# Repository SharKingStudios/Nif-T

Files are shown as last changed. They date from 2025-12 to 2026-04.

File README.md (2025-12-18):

<p align="center">
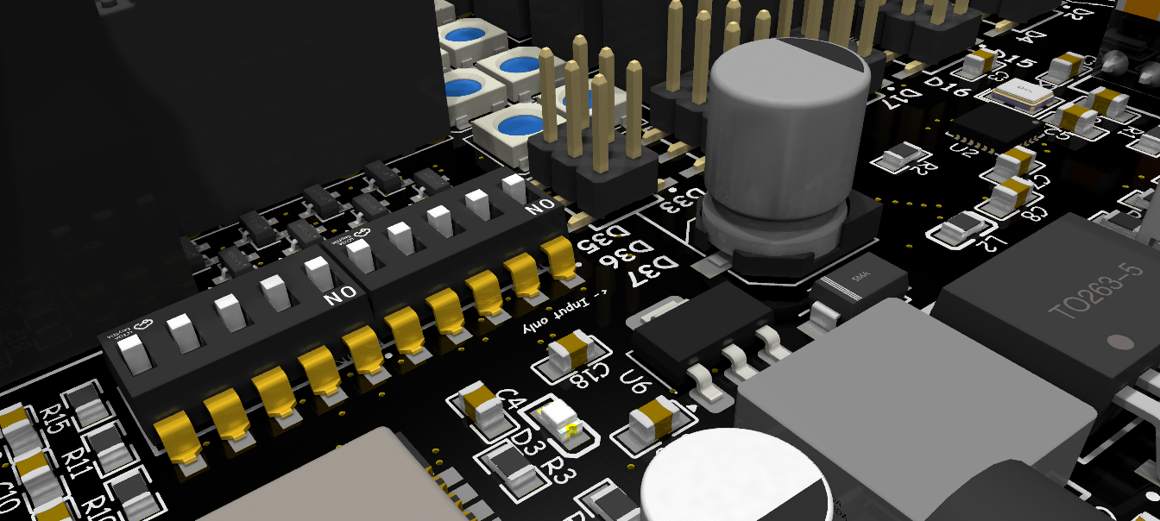
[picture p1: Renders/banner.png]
Banner
  
</p>

# Nif-T - An all in one smart home automation board

### A No-Nonsense Ethernet + PoE Smart-Home Controller

---

## Renders  
*Visuals because everyone loves eye candy.*

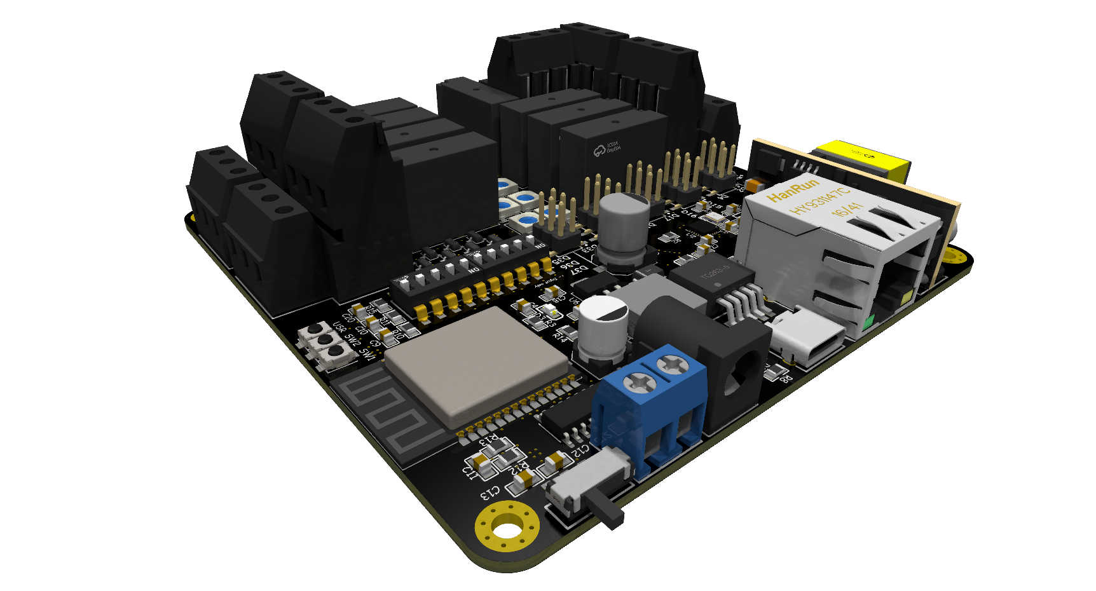
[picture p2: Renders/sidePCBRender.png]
Side PCB Render

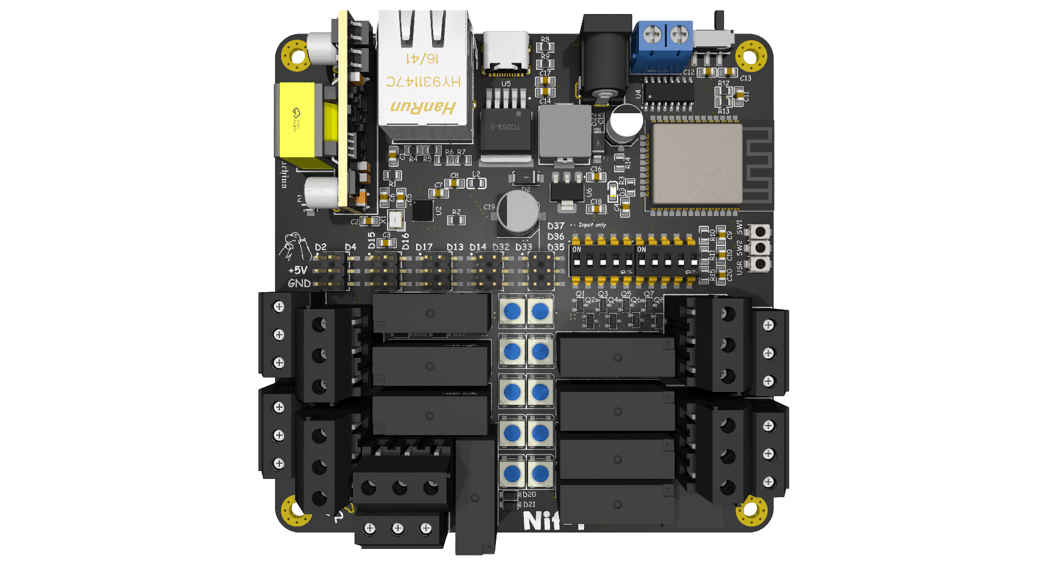
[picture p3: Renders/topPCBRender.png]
Top PCB Render

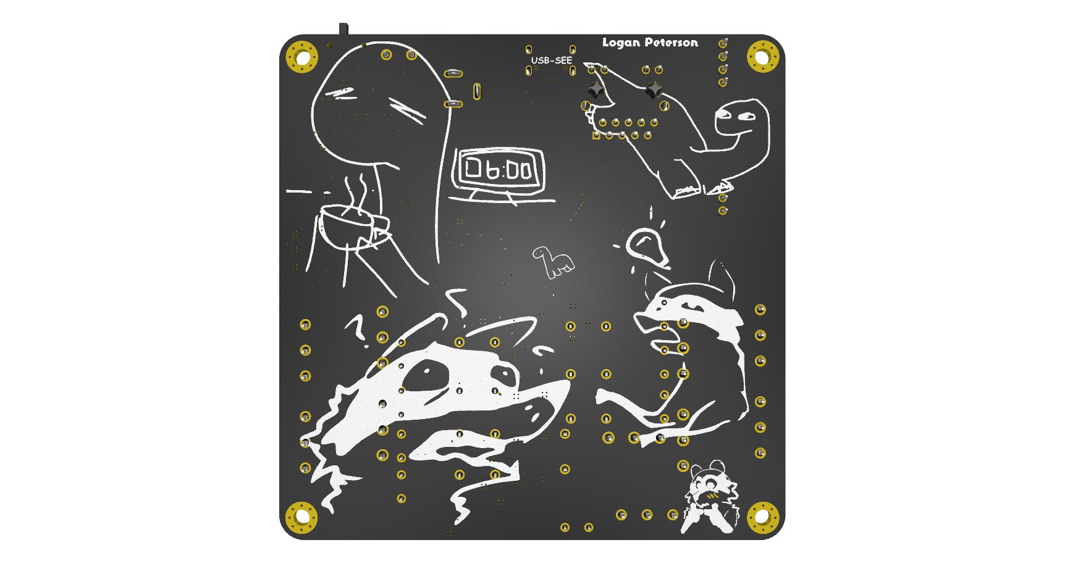
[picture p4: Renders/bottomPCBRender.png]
Bottom PCB Render

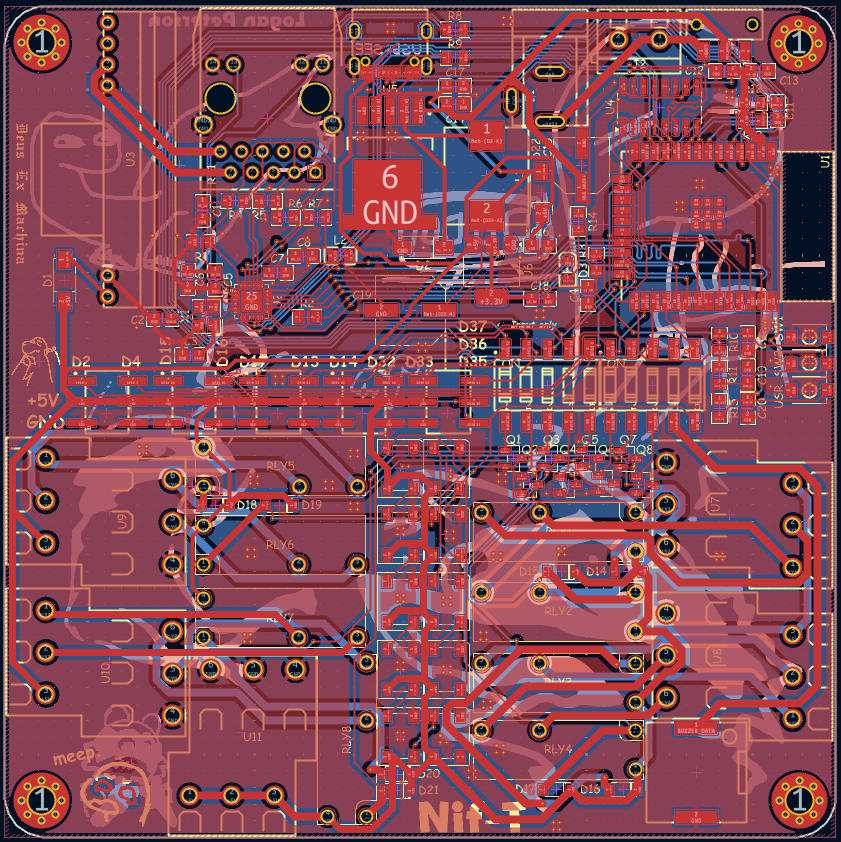
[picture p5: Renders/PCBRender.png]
Routing Glamour Shot

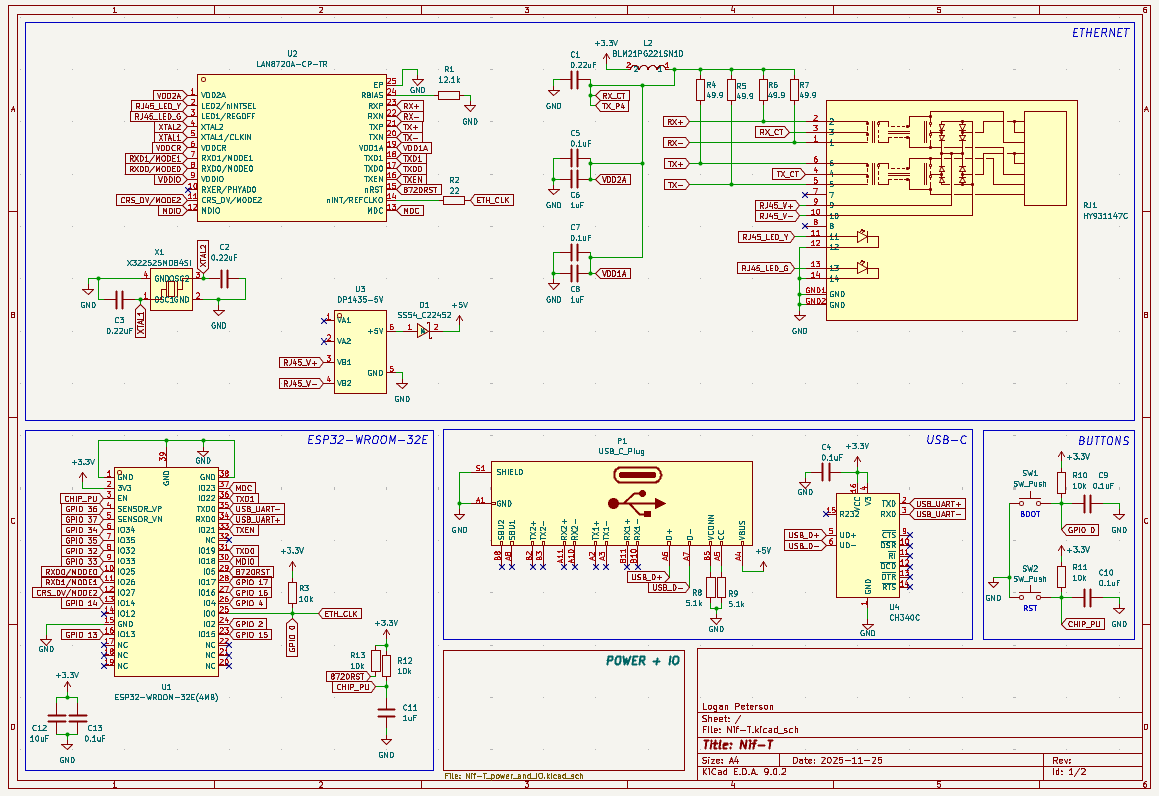
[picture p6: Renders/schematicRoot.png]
Schematic Picture

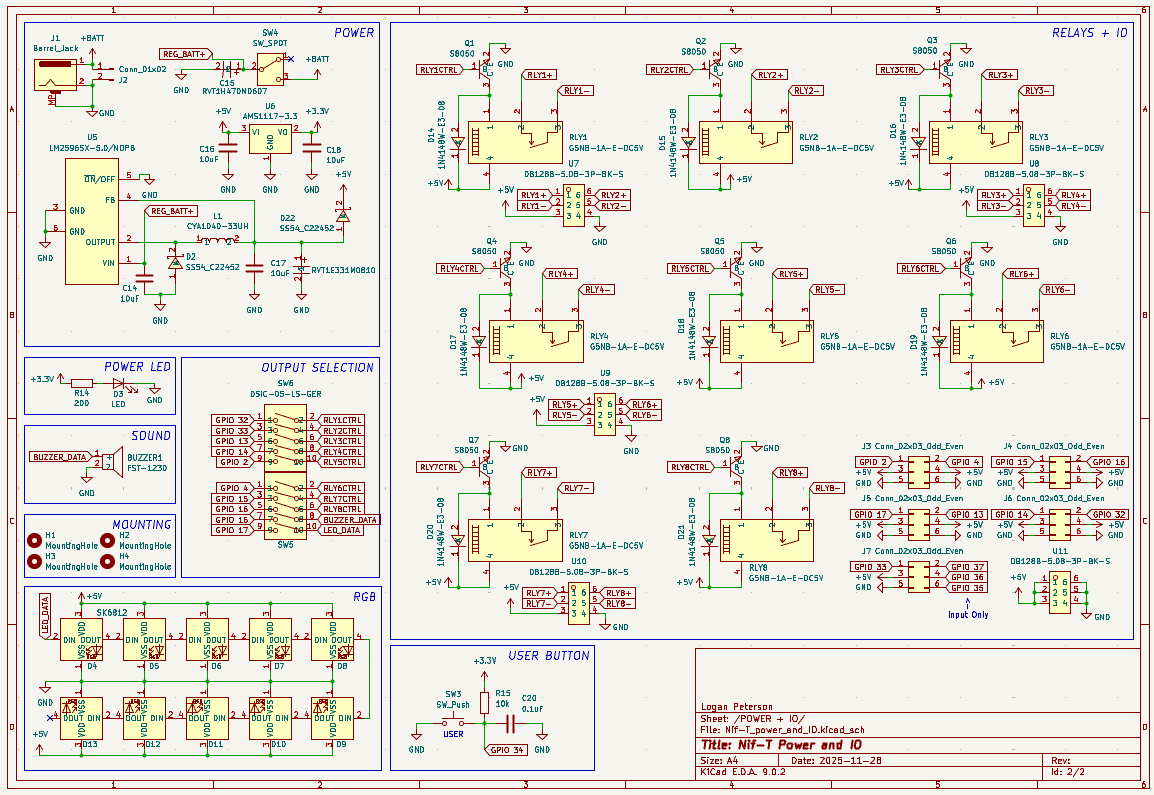
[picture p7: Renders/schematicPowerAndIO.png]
Schematic Picture


> *The middle ground planes are hidden in the PCB Routing render*

---

## BOM  
All the silicon, magnetics, and clicky-relay goodness live **[here](/BOM.csv)**.

**Main characters:**
- **MCU:** ESP32-WROOM-32E
- **Ethernet PHY:** LAN8720A (RMII, external 50 MHz oscillator)
- **Power over Ethernet:** IEEE 802.3af PoE (on-board PD + isolation)
- **Relays:** 8× PCB-mount power relays
- **RGB LEDs:** 10× SK6812 Mini
- **Buzzer:** On-board piezo
- **User Input:** Programmable user button
- **Connectivity:** Ethernet (primary), USB-UART for flashing/debug
- **Power:** PoE-powered with on-board regulation for ESP32 + peripherals
- **Misc:** Boot circuitry, reset logic, pull-ups, decoupling, and other necessary magic

(See `BOM.md` for full part values, footprints, and sourcing.)

---

## What is this?

**Nif-T** is a **wired smart-home automation controller** built around an **ESP32-WROOM-32E**, designed to be the thing that actually flips real switches when you ask your house to do something.

It’s meant for:
- **Lights**
- **Outlets**
- **Relays**
- **Buzzers**
- **Addressable LEDs**
- And other “turn this on when I say so” tasks

Unlike a lot of Wi-Fi-only smart devices, **Nif-T speaks Ethernet** — and it can be powered over the same cable using **PoE**. One cable in, automation out.

At a high level, Nif-T:
- Exposes **physical relays and LEDs**
- Talks to **Home Assistant**
- Which then talks to **Google Home**
- So you can say things like:

> *“Hey Google, turn on the big light.”*

…and something actually happens.

---

## Features

### Relay Control
- **8× independent relay outputs**
- Designed for:
  - Lighting circuits
  - Power control
  - Low-voltage automation tasks
- Each relay is individually addressable via firmware
- Can be controlled via:
  - MQTT
  - Home Assistant
  - Google Home (through HA)

*(Please don’t hot-switch mains unless you know what you’re doing.)*

---

### Ethernet + PoE
Because reliability matters — and wall warts are annoying.

- **LAN8720A Ethernet PHY**
  - RMII interface
  - Dedicated 50 MHz oscillator on the PHY
- **IEEE 802.3af Power over Ethernet**
  - Single-cable power + data
  - On-board PD controller and isolation
  - Clean DC rails generated locally
- No Wi-Fi congestion
- No random disconnects
- No external power brick required

Plug in Ethernet. That’s it.

---

### RGB Status LEDs
Because silent boards are boring.

- **10× SK6812 Mini (GRBW) LEDs**
- Can indicate:
  - Network status
  - MQTT / Home Assistant connection
  - Relay activity
  - Boot / error states
  - Or just run rainbow animations for morale
- Fully firmware-controlled

---

### Buttons & Feedback
- **User button**
  - Can be mapped to:
    - Toggle a relay
    - Enter config mode
    - Trigger a scene
- **On-board buzzer**
  - Boot beeps
  - Error alerts
  - Confirmation chirps
  - Mildly annoying sounds (optional but encouraged)

---

## Connectivity & IO

- **ESP32-WROOM-32E**
  - Dual-core MCU
  - Plenty of GPIO for:
    - Relays
    - LEDs
    - Buttons
    - Buzzers
- **USB-UART**
  - Firmware flashing
  - Serial debugging
- **Screw terminals**
  - For relays and power connections that shouldn’t wiggle loose

---

## Pin Highlights (High-Level)

| Function | Notes |
|---|---|
| Relays | 8× GPIO-controlled outputs |
| LED Data | SK6812 GRBW strip (10 LEDs) |
| Ethernet RMII | LAN8720A w/ external 50 MHz oscillator |
| PoE Input | IEEE 802.3af compliant |
| User Button | Input-only GPIO (external pull-ups) |
| Buzzer | GPIO-driven piezo output |

*(See schematic for full pin mapping and signal names.)*

---

## How It Works

At a high level:

1. **You plug in Ethernet** (which also provides power via PoE)
2. The **PoE PD negotiates power** and generates isolated DC rails
3. The **ESP32 boots** and brings up Ethernet
4. It connects to:
   - An **MQTT broker** (usually Home Assistant)
5. Home Assistant:
   - Discovers Nif-T automatically
   - Exposes relays and LEDs as entities
6. Google Home talks to Home Assistant
7. You talk to Google
8. Nif-T clicks relays and blinks LEDs

---

## Example Use Cases

- “Hey Google, turn on the **workbench lights**”
- “Turn off **everything downstairs**”
- LED status strip that shows:
  - Green = online
  - Red = offline
  - Blue = updating
- Physical button toggles a relay *and* triggers a Home Assistant scene
- Buzzer chirps when automations fire (or silently if you prefer)

---

## Why?

Because:
- Wi-Fi smart plugs are flaky
- Ethernet is king
- PoE makes installs clean
- And sometimes you just want a **solid, hackable, relay board** that plays nicely with modern home automation

Nif-T exists to be:
- Boring in the best way
- Reliable
- Predictable
- And extremely easy to integrate into a real automation stack

---

## Contribute

Ideas, improvements, and constructive roasting welcome.

- Open an **issue**
- Submit a **PR**
- Suggest features
- Argue about relay counts

---

## Disclaimer

This project is open-source, built for fun, and tested only in theory.

If you:
- Wire mains incorrectly
- Ignore clearance rules
- Overload a relay
- Or let the magic smoke out

That’s on you.

Be careful, be smart, and enjoy having a house that actually listens.

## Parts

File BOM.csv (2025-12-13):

Value | Qty | Price Ea. | Price total (MOQ) | LCSC link
RVT1H470M0607 (47uF 50V electrolytic) | 1 | 0.0292 | 0.58 | https://www.lcsc.com/product-detail/C72523.html
RVT1E331M0810 (330uF 25V electrolytic) | 1 | 0.0540 | 0.54 | https://www.lcsc.com/product-detail/C335985.html
1N4148W-E3-08 (SOD-123 fast diode) | 8 | 0.0308 | 0.15 | https://www.lcsc.com/product-detail/C241939.html
CYA1040-33UH (33uH inductor) | 1 | 0.3195 | 1.60 | https://www.lcsc.com/product-detail/C6364680.html
DC-005-A200 (Barrel jack) | 1 | 0.1108 | 0.55 | https://www.lcsc.com/product-detail/C720557.html
0.22uF 0805 | 3 | 0.02 | 0.55 | https://www.lcsc.com/product-detail/C5378.html
Power LED 0805 (D3) | 1 | 0.02 | 0.66 | https://www.lcsc.com/product-detail/C7371915.html
12.1k ohm 0805 (R1) | 1 | 0.03 | 0.73 | https://www.lcsc.com/product-detail/C865169.html
22 ohm 0805 (R2) | 1 | 0.002 | 0.20 | https://www.lcsc.com/product-detail/C17561.html
49.9 ohm 0805 | 4 | 0.002 | 0.18 | https://www.lcsc.com/product-detail/C2933455.html
5.1k ohm 0805 | 2 | 0.002 | 0.19 | https://www.lcsc.com/product-detail/C27834.html
10k ohm 0805 | 6 | 0.002 | 0.19 | https://www.lcsc.com/product-detail/C84376.html
200 ohm 0805 | 1 | 0.002 | 0.14 | https://www.lcsc.com/product-detail/C2933534.html
Crystal Oscillator X322525MOB4SI | 1 | 0.07 | 0.68 | https://www.lcsc.com/product-detail/C9006.html
AMS1117-3.3 | 1 | 0.16 | 0.83 | https://www.lcsc.com/product-detail/C6186.html
TI LM2596SX-5.0/NOPB | 1 | 0.86 | 0.86 | https://www.lcsc.com/product-detail/C10002.html
WCH CH340C | 1 | 0.54 | 0.54 | https://www.lcsc.com/product-detail/C84681.html
MICROCHIP LAN8720A-CP-TR | 1 | 0.73 | 0.73 | https://www.lcsc.com/product-detail/C45223.html
ESPRESSIF ESP32-WROOM-32E-N8 | 1 | 4.11 | 4.11 | https://www.lcsc.com/product-detail/C701342.html
USB-C Port | 1 | 0.05 | 0.49 | https://www.lcsc.com/product-detail/C2927038.html
Ethernet Port (With Magnetics) | 1 | 2.38 | 2.38 | https://www.lcsc.com/product-detail/C91754.html
FST-1230 (Buzzer) | 1 | 0.46 | 0.46 | https://www.lcsc.com/product-detail/C391037.html
SS54 (Schottky diode) | 3 | 0.05 | 0.43 | https://www.lcsc.com/product-detail/C22452.html
SK6812 RGB LED (5050) | 10 | 0.09 | 0.86 | https://www.lcsc.com/product-detail/C5378720.html
CL21B104KBCNNNC (0.1uF 50V X7R 0805) | 7 | 0.006 | 0.30 | https://www.lcsc.com/product-detail/C1711.html
CL21B105KBFNNNE (1uF 50V X7R 0805) | 3 | 0.009 | 0.18 | https://www.lcsc.com/product-detail/C28323.html
CL21A106KAYNNNE (10uF 25V X5R 0805) | 5 | 0.01 | 0.20 | https://www.lcsc.com/product-detail/C15850.html
BLM21PG221SN1D (ferrite bead) | 1 | 0.02 | 0.82 | https://www.lcsc.com/product-detail/C85840.html
S8050 NPN transistor | 8 | 0.0057 | 0.57 | https://www.lcsc.com/product-detail/C916390.html
OMRON G5NB-1A-E-DC5V | 8 | 0.43 | 3.37 | https://www.lcsc.com/product-detail/C48746.html
KF301-5.0-2P (5.00mm 2P terminal block) | 1 | 0.09 | 0.44 | https://www.lcsc.com/product-detail/C474881.html
ZHOURI PZ2.54-2*20-SMT | 2 | 0.24 | 1.2 | https://www.lcsc.com/product-detail/C5378173.html
DORABO DB128B-5.08-2*3P-BK-S | 5 | 0.65 | 3.20 | https://www.lcsc.com/product-detail/C500038.html
SDAPO DP1435-5V | 1 | 4.94 | 4.94 | https://www.lcsc.com/product-detail/C5380097.html
XUNPU DSIC-05-LS-GER | 2 | 0.32 | 0.63 | https://www.lcsc.com/product-detail/C7471367.html
XUNPU TS-1088-AR02016 | 3 | 0.05 | 0.42 | https://www.lcsc.com/product-detail/C720477.html
MST-12D18G4 SPDT Slide Switch | 1 | 0.08 | 0.36 | https://www.lcsc.com/product-detail/C49023767.html
SK6812MINI-HS (extra for dif proj) | 80 | 0.08 | 6.18 | https://www.lcsc.com/product-detail/C2922787.html
LCSC Merchandise Subtotal |  |  |  | 41.96
LCSC Shipping Estimate |  |  |  | 15.12
LCSC Taxes Buffer |  |  |  | 5.00
LCSC Total |  |  |  | 62.08
JLCPCB Fabrication | 5 |  |  | 2.00
JLCPCB Stencil | 1 |  |  | 7.00
JLCPCB Shipping Estimate |  |  |  | 16.50
JLCPCB Taxes Buffer |  |  |  | 3.00
JLCPCB Total |  |  |  | 28.50
Grand Total |  |  |  | 90.58
Reimbursement amount |  |  |  | 6.18

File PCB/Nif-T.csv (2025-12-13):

Reference | Qty | Value | DNP | Exclude from BOM | Exclude from Board | Footprint | Datasheet
BUZZER1 | 1 | FST-1230 |  |  |  | imported_components:BUZ-SMD_L12.0-W12.0_FUET-1230 | https://lcsc.com/product-detail/Buzzers_FST-FST-1230_C391037.html
C1,C2,C3 | 3 | 0.22uF |  |  |  | imported_components:C0805 | ~
C4,C5,C7,C9,C10,C13,C20 | 7 | 0.1uF |  |  |  | imported_components:C0805 | ~
C6,C8,C11 | 3 | 1uF |  |  |  | imported_components:C0805 | ~
C12,C14,C16,C17,C18 | 5 | 10uF |  |  |  | imported_components:C0805 | ~
C15 | 1 | RVT1H470M0607 |  |  |  | imported_components:CAP-SMD_BD6.3-L6.6-W6.6-LS7.6-FD | https://lcsc.com/product-detail/Aluminum-Electrolytic-Capacitors-SMD_47uF-50V-20_C72523.html
C19 | 1 | RVT1E331M0810 |  |  |  | imported_components:CAP-SMD_BD8.0-L8.3-W8.3-LS9.3-FD-1 | https://lcsc.com/product-detail/Others_ROQANG-RVT1E331M0810_C335985.html
D1,D2,D22 | 3 | SS54_C22452 |  |  |  | imported_components:SMA_L4.4-W2.8-LS5.4-R-RD | https://lcsc.com/product-detail/Schottky-Barrier-Diodes-SBD_SS54_C22452.html
D3 | 1 | LED |  |  |  | imported_components:LED0805-RD | ~
D4,D5,D6,D7,D8,D9,D10,D11,D12,D13 | 10 | SK6812 |  |  |  | LED_SMD:LED_SK6812_PLCC4_5.0x5.0mm_P3.2mm | https://cdn-shop.adafruit.com/product-files/1138/SK6812+LED+datasheet+.pdf
D14,D15,D16,D17,D18,D19,D20,D21 | 8 | 1N4148W-E3-08 |  |  |  | new_imported_components:SOD-123_L2.8-W1.8-LS3.7-RD | https://lcsc.com/product-detail/Others_Vishay-Intertech_1N4148W-E3-08_Vishay-Intertech-1N4148W-E3-08_C241939.html
H1,H2,H3,H4 | 4 | MountingHole |  | Excluded from BOM |  | MountingHole:MountingHole_3.2mm_M3_Pad_Via | ~
J1 | 1 | Barrel_Jack |  |  |  | imported_components:DC-IN-TH_DC-005-A200 | ~
J2 | 1 | Conn_01x02 |  |  |  | imported_components:CONN-TH_P5.00_KF301-5.0-2P | ~
J3,J4,J5,J6,J7 | 5 | Conn_02x03_Odd_Even |  |  |  | imported_components:HDR-SMD_6P-P2.54-V | ~
L1 | 1 | CYA1040-33UH |  |  |  | imported_components:IND-SMD_L11.6-W10.1
L2 | 1 | BLM21PG221SN1D |  |  |  | new_imported_components:L0805 | https://lcsc.com/product-detail/Ferrite-Beads-And-Chips_muRata_BLM21PG221SN1D_220R-25-at100MHz-2A_C85840.html
P1 | 1 | USB_C_Plug |  |  |  | imported_components:USB-C_SMD-TYPE-C-31-M-12 | https://www.usb.org/sites/default/files/documents/usb_type-c.zip
Q1,Q2,Q3,Q4,Q5,Q6,Q7,Q8 | 8 | S8050 |  |  |  | new_imported_components:SOT-23-3_L2.9-W1.3-P1.90-LS2.4-BR | https://lcsc.com/product-detail/Transistors-NPN-PNP_JSMSEMI-S8050_C916390.html
R1 | 1 | 12.1k |  |  |  | imported_components:R0805 | ~
R2 | 1 | 22 |  |  |  | imported_components:R0805 | ~
R3,R10,R11,R12,R13,R15 | 6 | 10k |  |  |  | imported_components:R0805 | ~
R4,R5,R6,R7 | 4 | 49.9 |  |  |  | imported_components:R0805 | ~
R8,R9 | 2 | 5.1k |  |  |  | imported_components:R0805 | ~
R14 | 1 | 200 |  |  |  | imported_components:R0805 | ~
RJ1 | 1 | HY931147C |  |  |  | new_imported_components:RJ45-TH_HY931147C | https://lcsc.com/product-detail/RJ45_HY931147C_C91754.html
RLY1,RLY2,RLY3,RLY4,RLY5,RLY6,RLY7,RLY8 | 8 | G5NB-1A-E-DC5V |  |  |  | new_imported_components:RELAY-TH_G5NB-1A-E-DCXX | https://lcsc.com/product-detail/Relays_OMRON_G5NB-1A-E-DC5V_G5NB-1A-E-DC5V_C48746.html
SW1,SW2,SW3 | 3 | SW_Push |  |  |  | imported_components:SW-SMD_L3.9-W3.0-P4.45 | ~
SW4 | 1 | SW_SPDT |  |  |  | imported_components:SW-SMD_MST-12D18G4-SPDT-SLIDE-SWITCH | ~
SW5,SW6 | 2 | DSIC-05-LS-GER |  |  |  | new_imported_components:SW-SMD_DSIC-05-LS-GER
U1 | 1 | ESP32-WROOM-32E(4MB) |  |  |  | new_imported_components:WIFI-SMD_ESP32-WROOM-32E | https://lcsc.com/product-detail/WIFI-Modules_Espressif-Systems-ESP32-WROOM-32E-4MB_C701341.html
U2 | 1 | LAN8720A-CP-TR |  |  |  | new_imported_components:QFN-24_L4.0-W4.0-P0.50-BL-EP2.6 | https://lcsc.com/product-detail/Ethernet-ICs_LAN8720A-CP-TR_C45223.html
U3 | 1 | DP1435-5V |  |  |  | new_imported_components:PWRM-TH_DP1435-XX
U4 | 1 | CH340C |  |  |  | Package_SO:SOIC-16_3.9x9.9mm_P1.27mm | https://datasheet.lcsc.com/szlcsc/Jiangsu-Qin-Heng-CH340C_C84681.pdf
U5 | 1 | LM2596SX-5.0/NOPB |  |  |  | imported_components:TO-263-5_L10.2-W8.9-P1.70-TL | https://lcsc.com/product-detail/DC-DC-Converters_TI_LM2596SX-5-0-NOPB_LM2596SX-5-0-NOPB_C10002.html
U6 | 1 | AMS1117-3.3 |  |  |  | Package_TO_SOT_SMD:SOT-223-3_TabPin2 | http://www.advanced-monolithic.com/pdf/ds1117.pdf
U7,U8,U9,U10,U11 | 5 | DB128B-5.08-3P-BK-S |  |  |  | new_imported_components:CONN-TH_DB128B-5.08-3P-XX-S | https://lcsc.com/product-detail/New-Arrivals_DIBO-DB128B-5-08-3P-BK-S_C500038.html
X1 | 1 | X322525MOB4SI |  |  |  | new_imported_components:CRYSTAL-SMD_4P-L3.2-W2.5-BL | https://lcsc.com/product-detail/SMD-Crystals_YSX321SL-25MHZ-12PF-10PPM-40-85_C9006.html

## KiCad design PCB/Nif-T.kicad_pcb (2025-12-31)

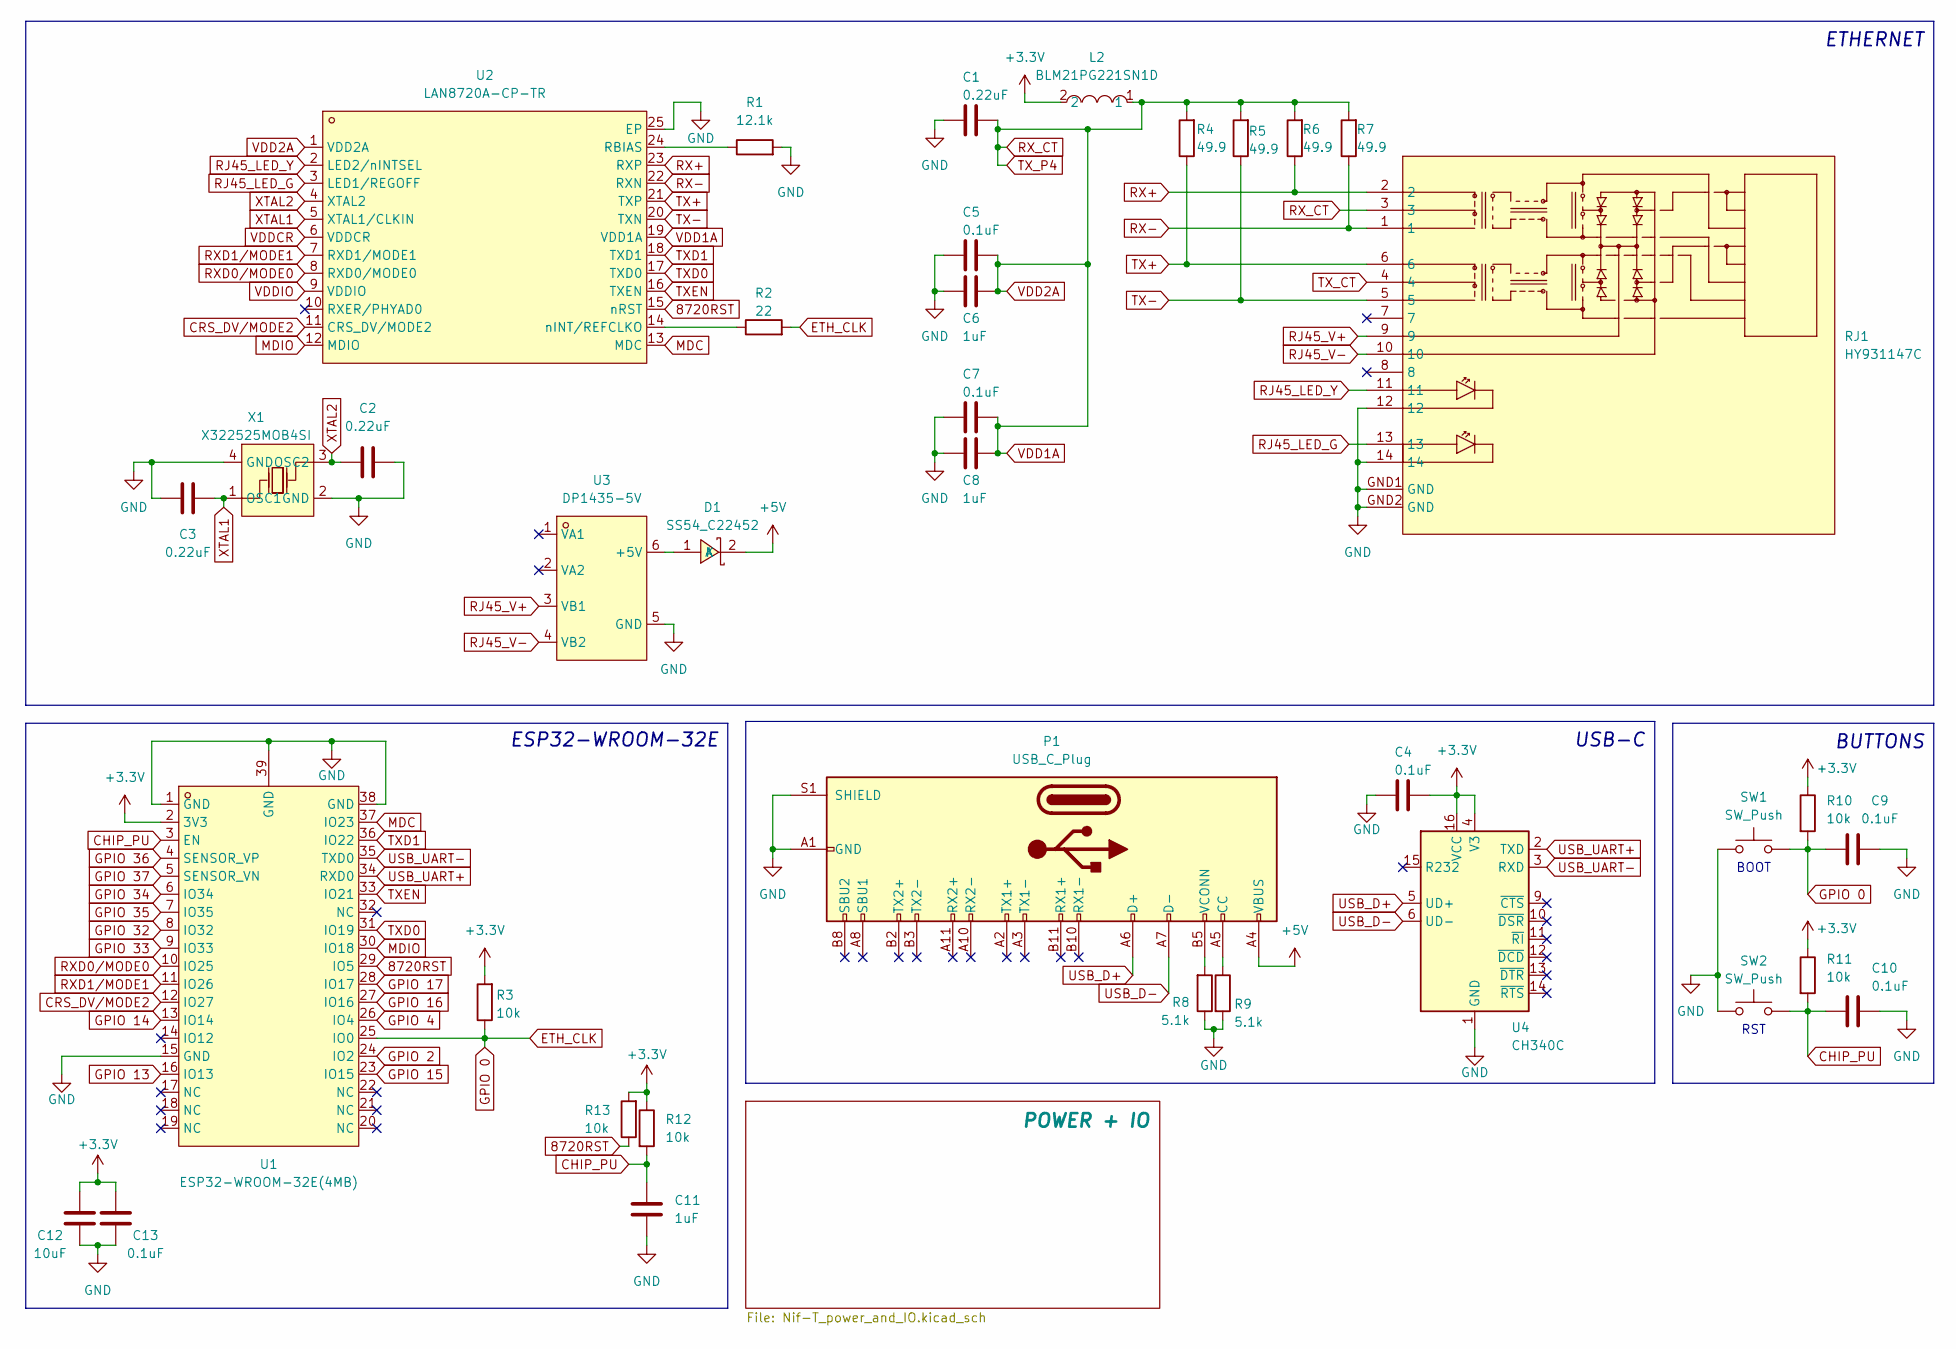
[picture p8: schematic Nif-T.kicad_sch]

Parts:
C1, C2, C3: 0.22uF; C0805
C4, C5, C7, C9, C10, C13: 0.1uF; C0805
C6, C8, C11: 1uF; C0805
C12: 10uF; C0805
D1: SS54_C22452; SMA_L4.4-W2.8-LS5.4-R-RD; LCSC Part C22452
L2: BLM21PG221SN1D; L0805; LCSC Part C85840
P1: USB_C_Plug; USB-C_SMD-TYPE-C-31-M-12
R1: 12.1k; R0805
R2: 22; R0805
R3, R10, R11, R12, R13: 10k; R0805
R4, R5, R6, R7: 49.9; R0805
R8, R9: 5.1k; R0805
RJ1: HY931147C; RJ45-TH_HY931147C; LCSC Part C91754
SW1, SW2: SW_Push; SW-SMD_L3.9-W3.0-P4.45
U1: ESP32-WROOM-32E(4MB); WIFI-SMD_ESP32-WROOM-32E; LCSC Part C701341
U2: LAN8720A-CP-TR; QFN-24_L4.0-W4.0-P0.50-BL-EP2.6; LCSC Part C45223
U3: DP1435-5V; PWRM-TH_DP1435-XX; LCSC Part C5380097
U4: CH340C; SOIC-16_3.9x9.9mm_P1.27mm
X1: X322525MOB4SI; CRYSTAL-SMD_4P-L3.2-W2.5-BL; LCSC Part C9006

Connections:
8720RST: R13.1, U1.29 (IO5), U2.15 (nRST)
+3.3V: C4.1, C12.2, C13.2, L2.2, R3.2, R10.1, R11.1, R12.1, R13.2, U1.2 (3V3), U4.4 (V3), U4.16 (VCC); also elsewhere on the board
+5V: D1.2 (K), P1.A4 (VBUS), P1.A9 (VBUS), P1.B4 (VBUS), P1.B9 (VBUS); also elsewhere on the board
CHIP_PU: C10.1, C11.1, R11.2, R12.2, SW2.1, U1.3 (EN)
CRS_DV/MODE2: U1.12 (IO27), U2.11 (CRS_DV/MODE2)
ETH_CLK: C9.1, R2.2, R3.1, R10.2, SW1.1, U1.25 (IO0)
GND: C1.2, C2.2, C3.1, C4.2, C5.2, C6.2, C7.2, C8.2, C9.2, C10.2, C11.2, C12.1, C13.1, P1.A1 (GND), P1.A12 (GND), P1.B1 (GND), P1.B12 (GND), P1.S1 (SHIELD), R1.2, R8.1, R9.2, RJ1.12, RJ1.14, RJ1.GND1 (GND), RJ1.GND2 (GND), SW1.2, SW2.2, U1.1 (GND), U1.15 (GND), U1.38 (GND), U1.39 (GND), U2.25 (EP), U3.5 (GND), U4.1 (GND), X1.2 (GND), X1.4 (GND); also elsewhere on the board
GPIO 2: U1.24 (IO2); also elsewhere on the board
GPIO 4: U1.26 (IO4); also elsewhere on the board
GPIO 13: U1.16 (IO13); also elsewhere on the board
GPIO 14: U1.13 (IO14); also elsewhere on the board
GPIO 15: U1.23 (IO15); also elsewhere on the board
GPIO 16: U1.27 (IO16); also elsewhere on the board
GPIO 17: U1.28 (IO17); also elsewhere on the board
GPIO 32: U1.8 (IO32); also elsewhere on the board
GPIO 33: U1.9 (IO33); also elsewhere on the board
GPIO 34: U1.6 (IO34); also elsewhere on the board
GPIO 35: U1.7 (IO35); also elsewhere on the board
GPIO 36: U1.4 (SENSOR_VP); also elsewhere on the board
GPIO 37: U1.5 (SENSOR_VN); also elsewhere on the board
MDC: U1.37 (IO23), U2.13 (MDC)
MDIO: U1.30 (IO18), U2.12 (MDIO)
unnamed: D1.1 (A), U3.6 (+5V)
unnamed: P1.A5 (CC), R9.1
unnamed: P1.B5 (VCONN), R8.2
unnamed: R1.1, U2.24 (RBIAS)
unnamed: R2.1, U2.14 (nINT/REFCLKO)
RJ45_LED_G: RJ1.13, U2.3 (LED1/REGOFF)
RJ45_LED_Y: RJ1.11, U2.2 (LED2/nINTSEL)
RJ45_V+: RJ1.9, U3.3 (VB1)
RJ45_V-: RJ1.10, U3.4 (VB2)
RX+: R6.1, RJ1.2, U2.23 (RXP)
RX-: R7.1, RJ1.1, U2.22 (RXN)
RXD0/MODE0: U1.10 (IO25), U2.8 (RXD0/MODE0)
RXD1/MODE1: U1.11 (IO26), U2.7 (RXD1/MODE1)
RX_CT: C1.1, C5.1, C6.1, C7.1, C8.1, L2.1, R4.2, R5.2, R6.2, R7.2, RJ1.3, U2.1 (VDD2A), U2.19 (VDD1A)
TX+: R4.1, RJ1.6, U2.21 (TXP)
TX-: R5.1, RJ1.5, U2.20 (TXN)
TXD0: U1.31 (IO19), U2.17 (TXD0)
TXD1: U1.36 (IO22), U2.18 (TXD1)
TXEN: U1.33 (IO21), U2.16 (TXEN)
TX_CT: RJ1.4
USB_D+: P1.A6 (D+), U4.5 (UD+)
USB_D-: P1.A7 (D-), U4.6 (UD-)
USB_UART+: U1.34 (RXD0), U4.2 (TXD)
USB_UART-: U1.35 (TXD0), U4.3 (RXD)
VDDCR: U2.6 (VDDCR)
VDDIO: U2.9 (VDDIO)
XTAL1: C3.2, U2.5 (XTAL1/CLKIN), X1.1 (OSC1)
XTAL2: C2.1, U2.4 (XTAL2), X1.3 (OSC2)

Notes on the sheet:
BOOT
ESP32-WROOM-32E
ETHERNET
RST
USB-C
BUTTONS

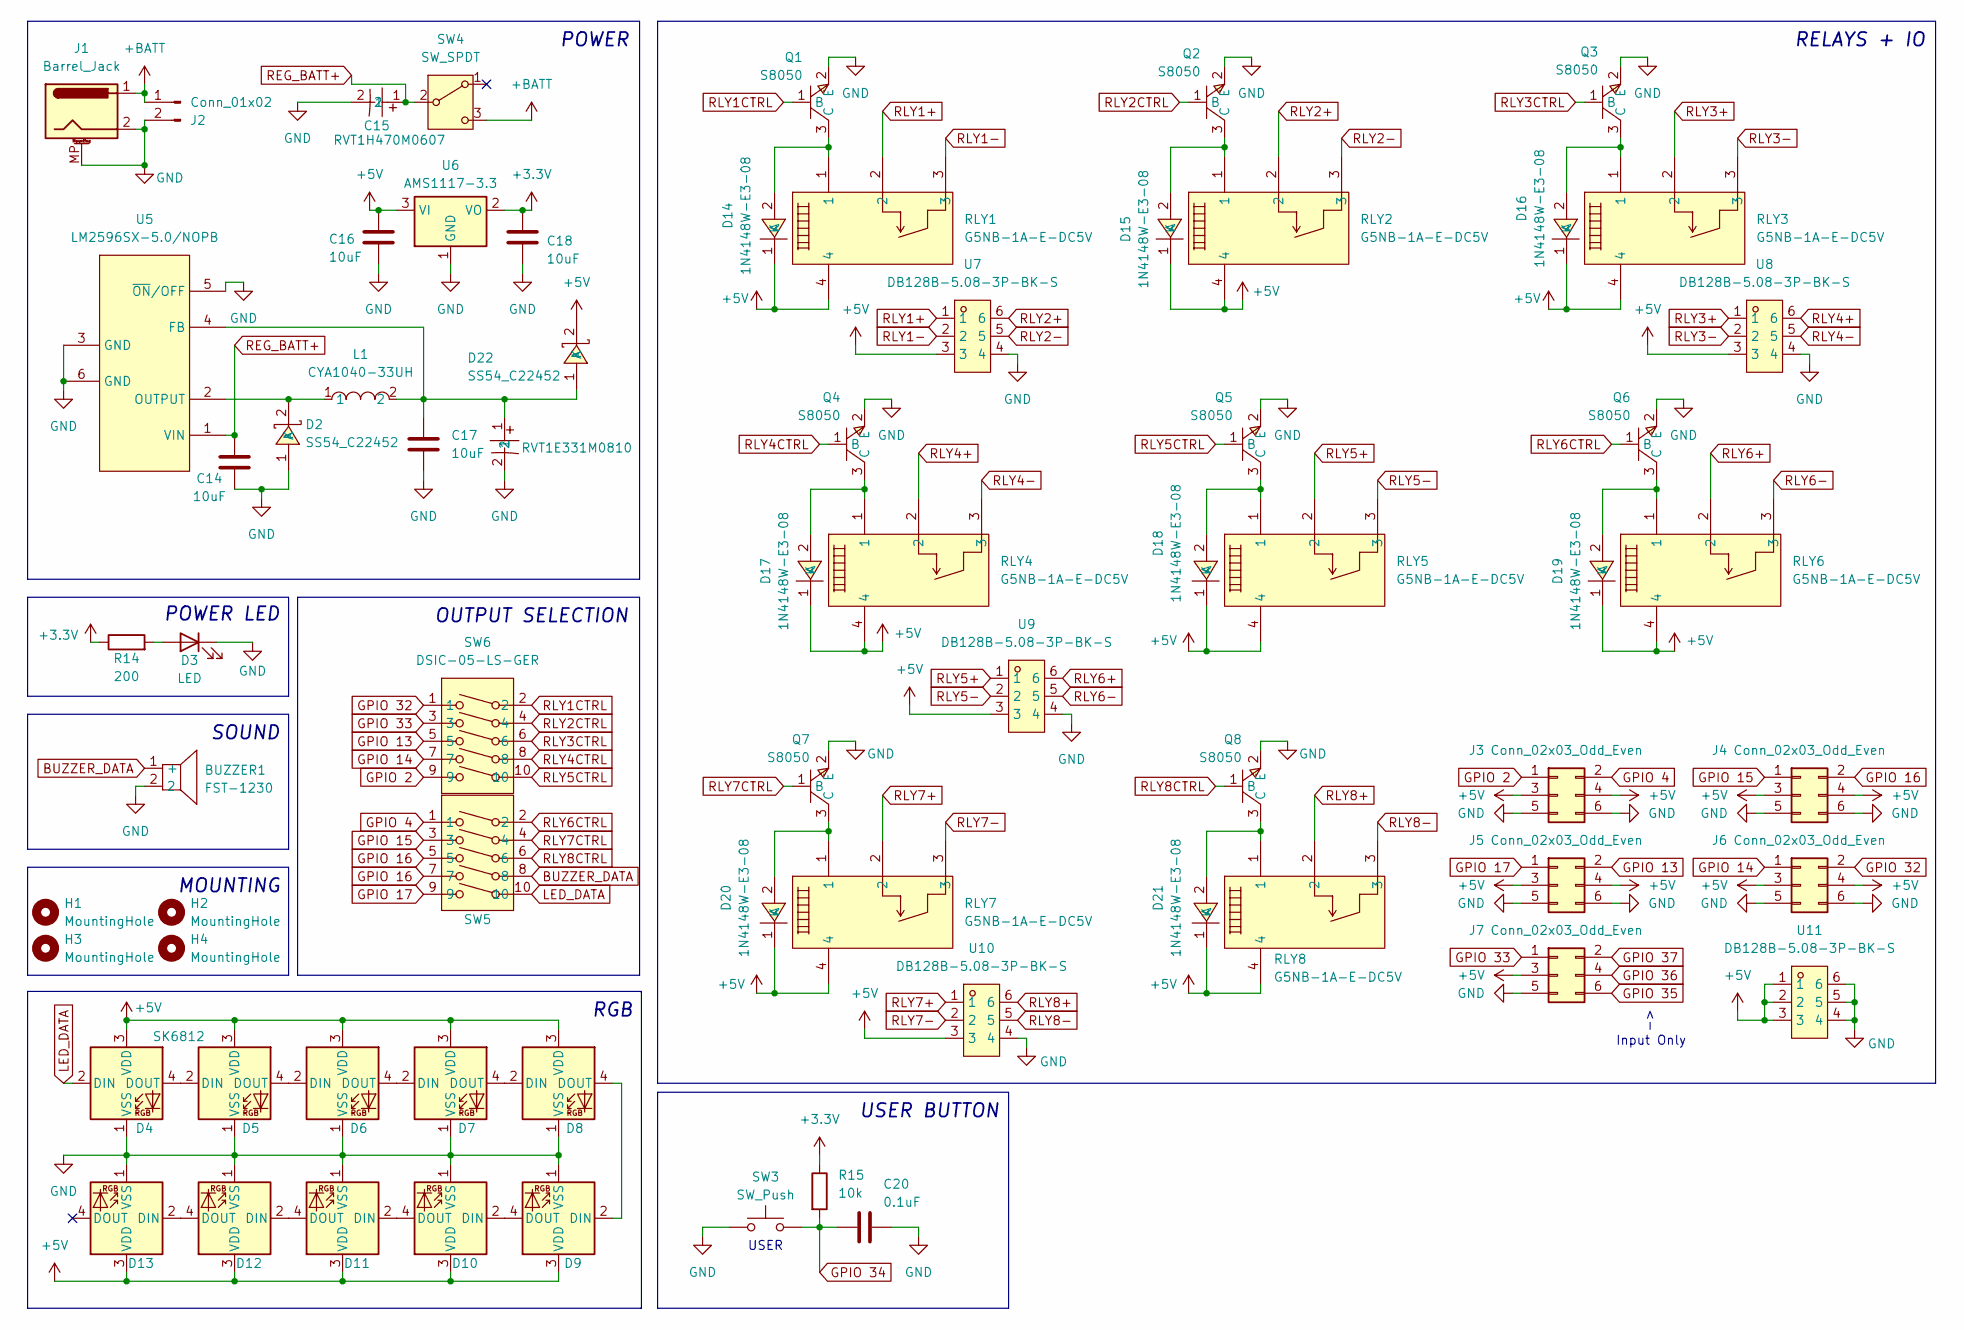
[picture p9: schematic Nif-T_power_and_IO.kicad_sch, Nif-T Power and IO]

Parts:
BUZZER1: FST-1230; BUZ-SMD_L12.0-W12.0_FUET-1230; LCSC Part C391037
C14, C16, C17, C18: 10uF; C0805
C15: RVT1H470M0607; CAP-SMD_BD6.3-L6.6-W6.6-LS7.6-FD; LCSC Part C72523
C19: RVT1E331M0810; CAP-SMD_BD8.0-L8.3-W8.3-LS9.3-FD-1; LCSC Part C335985
C20: 0.1uF; C0805
D2, D22: SS54_C22452; SMA_L4.4-W2.8-LS5.4-R-RD; LCSC Part C22452
D3: LED; LED0805-RD
D4, D5, D6, D7, D8, D9, D10, D11, D12, D13: SK6812; LED_SK6812_PLCC4_5.0x5.0mm_P3.2mm
D14, D15, D16, D17, D18, D19, D20, D21: 1N4148W-E3-08; SOD-123_L2.8-W1.8-LS3.7-RD; LCSC Part C241939
H1, H2, H3, H4: MountingHole; MountingHole_3.2mm_M3_Pad_Via
J1: Barrel_Jack; DC-IN-TH_DC-005-A200
J2: Conn_01x02; CONN-TH_P5.00_KF301-5.0-2P
J3, J4, J5, J6, J7: Conn_02x03_Odd_Even; HDR-SMD_6P-P2.54-V
L1: CYA1040-33UH; IND-SMD_L11.6-W10.1; LCSC Part C6364680
Q1, Q2, Q3, Q4, Q5, Q6, Q7, Q8: S8050; SOT-23-3_L2.9-W1.3-P1.90-LS2.4-BR; LCSC Part C916390
R14: 200; R0805
R15: 10k; R0805
RLY1, RLY2, RLY3, RLY4, RLY5, RLY6, RLY7, RLY8: G5NB-1A-E-DC5V; RELAY-TH_G5NB-1A-E-DCXX; LCSC Part C48746
SW3: SW_Push; SW-SMD_L3.9-W3.0-P4.45
SW4: SW_SPDT; SW-SMD_MST-12D18G4-SPDT-SLIDE-SWITCH
SW5, SW6: DSIC-05-LS-GER; SW-SMD_DSIC-05-LS-GER; LCSC Part C7471367
U5: LM2596SX-5.0/NOPB; TO-263-5_L10.2-W8.9-P1.70-TL; LCSC Part C10002
U6: AMS1117-3.3; SOT-223-3_TabPin2
U7, U8, U9, U10, U11: DB128B-5.08-3P-BK-S; CONN-TH_DB128B-5.08-3P-XX-S; LCSC Part C500038

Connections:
+3.3V: C18.1, R14.1, R15.1, U6.2 (VO); also elsewhere on the board
+5V: C16.1, D4.3 (VDD), D5.3 (VDD), D6.3 (VDD), D7.3 (VDD), D8.3 (VDD), D9.3 (VDD), D10.3 (VDD), D11.3 (VDD), D12.3 (VDD), D13.3 (VDD), D14.1 (K), D15.1 (K), D16.1 (K), D17.1 (K), D18.1 (K), D19.1 (K), D20.1 (K), D21.1 (K), D22.2 (K), J3.3, J3.4, J4.3, J4.4, J5.3, J5.4, J6.3, J6.4, J7.3, RLY1.4, RLY2.4, RLY3.4, RLY4.4, RLY5.4, RLY6.4, RLY7.4, RLY8.4, U6.3 (VI), U7.3, U8.3, U9.3, U10.3, U11.1, U11.2, U11.3; also elsewhere on the board
+BATT: J1.1, J2.1, SW4.3 (C)
BUZZER_DATA: BUZZER1.1 (+), SW5.8
GND: BUZZER1.2, C14.1, C15.2, C16.2, C17.2, C18.2, C19.2, C20.2, D2.1 (A), D3.1 (K), D4.1 (VSS), D5.1 (VSS), D6.1 (VSS), D7.1 (VSS), D8.1 (VSS), D9.1 (VSS), D10.1 (VSS), D11.1 (VSS), D12.1 (VSS), D13.1 (VSS), J1.2, J1.MP (MountPin), J2.2, J3.5, J3.6, J4.5, J4.6, J5.5, J5.6, J6.5, J6.6, J7.5, Q1.2 (E), Q2.2 (E), Q3.2 (E), Q4.2 (E), Q5.2 (E), Q6.2 (E), Q7.2 (E), Q8.2 (E), SW3.2, U5.3 (GND), U5.5 (~ON/OFF), U5.6 (GND), U6.1 (GND), U7.4, U8.4, U9.4, U10.4, U11.4, U11.5, U11.6; also elsewhere on the board
GPIO 2: J3.1, SW6.9; also elsewhere on the board
GPIO 4: J3.2, SW5.1; also elsewhere on the board
GPIO 13: J5.2, SW6.5; also elsewhere on the board
GPIO 14: J6.1, SW6.7; also elsewhere on the board
GPIO 15: J4.1, SW5.3; also elsewhere on the board
GPIO 16: J4.2, SW5.5, SW5.7; also elsewhere on the board
GPIO 17: J5.1, SW5.9; also elsewhere on the board
GPIO 32: J6.2, SW6.1; also elsewhere on the board
GPIO 33: J7.1, SW6.3; also elsewhere on the board
GPIO 34: C20.1, R15.2, SW3.1; also elsewhere on the board
GPIO 35: J7.6; also elsewhere on the board
GPIO 36: J7.4; also elsewhere on the board
GPIO 37: J7.2; also elsewhere on the board
LED_DATA: D4.2 (DIN), SW5.10
unnamed: D2.2 (K), L1.1, U5.2 (OUTPUT)
unnamed: D3.2 (A), R14.2
unnamed: D4.4 (DOUT), D5.2 (DIN)
unnamed: D5.4 (DOUT), D6.2 (DIN)
unnamed: D6.4 (DOUT), D7.2 (DIN)
unnamed: D7.4 (DOUT), D8.2 (DIN)
unnamed: D8.4 (DOUT), D9.2 (DIN)
unnamed: D9.4 (DOUT), D10.2 (DIN)
unnamed: D10.4 (DOUT), D11.2 (DIN)
unnamed: D11.4 (DOUT), D12.2 (DIN)
unnamed: D12.4 (DOUT), D13.2 (DIN)
unnamed: D14.2 (A), Q1.3 (C), RLY1.1
unnamed: D15.2 (A), Q2.3 (C), RLY2.1
unnamed: D16.2 (A), Q3.3 (C), RLY3.1
unnamed: D17.2 (A), Q4.3 (C), RLY4.1
unnamed: D18.2 (A), Q5.3 (C), RLY5.1
unnamed: D19.2 (A), Q6.3 (C), RLY6.1
unnamed: D20.2 (A), Q7.3 (C), RLY7.1
unnamed: D21.2 (A), Q8.3 (C), RLY8.1
unnamed: C17.1, C19.1, D22.1 (A), L1.2, U5.4 (FB)
REG_BATT+: C14.2, C15.1, SW4.2 (B), U5.1 (VIN)
RLY1+: RLY1.2, U7.1
RLY1-: RLY1.3, U7.2
RLY1CTRL: Q1.1 (B), SW6.2
RLY2+: RLY2.2, U7.6
RLY2-: RLY2.3, U7.5
RLY2CTRL: Q2.1 (B), SW6.4
RLY3+: RLY3.2, U8.1
RLY3-: RLY3.3, U8.2
RLY3CTRL: Q3.1 (B), SW6.6
RLY4+: RLY4.2, U8.6
RLY4-: RLY4.3, U8.5
RLY4CTRL: Q4.1 (B), SW6.8
RLY5+: RLY5.2, U9.1
RLY5-: RLY5.3, U9.2
RLY5CTRL: Q5.1 (B), SW6.10
RLY6+: RLY6.2, U9.6
RLY6-: RLY6.3, U9.5
RLY6CTRL: Q6.1 (B), SW5.2
RLY7+: RLY7.2, U10.1
RLY7-: RLY7.3, U10.2
RLY7CTRL: Q7.1 (B), SW5.4
RLY8+: RLY8.2, U10.6
RLY8-: RLY8.3, U10.5
RLY8CTRL: Q8.1 (B), SW5.6

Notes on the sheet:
POWER LED
OUTPUT SELECTION
SOUND
RELAYS + IO
USER
RGB
USER BUTTON
MOUNTING
POWER
Input Only

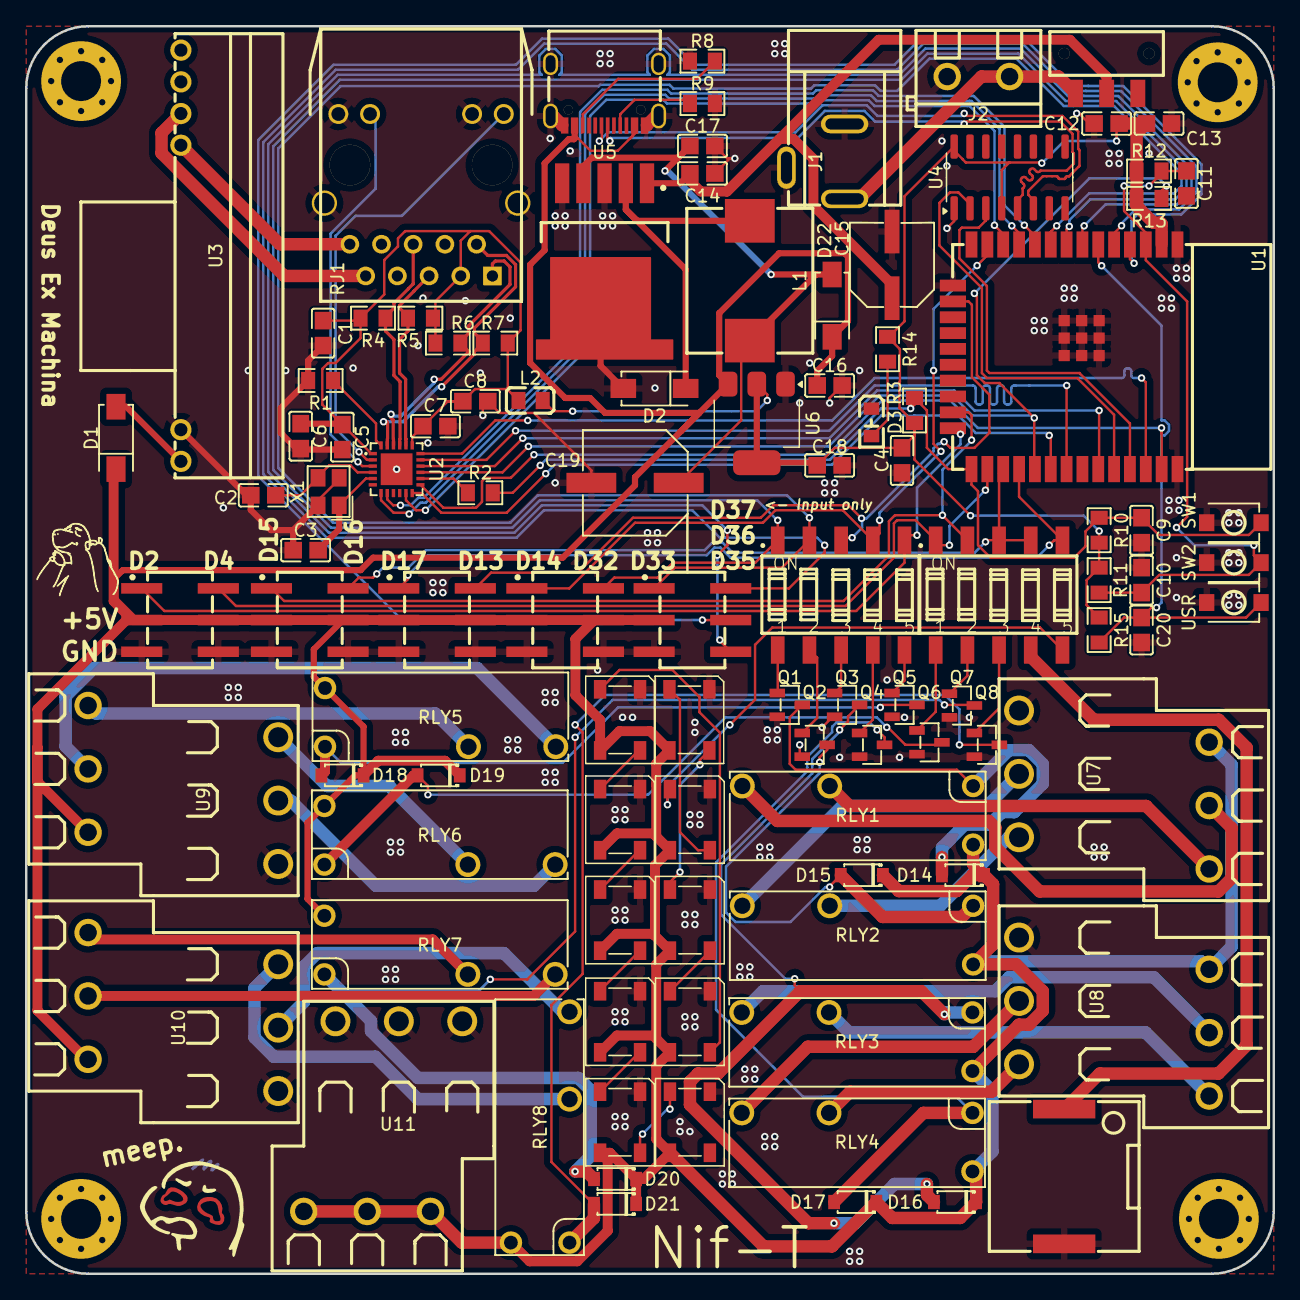
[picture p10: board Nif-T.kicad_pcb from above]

Board: 4 copper layers, 100.0 x 100.0 mm, 107 parts (0 on the bottom side), 95 nets.

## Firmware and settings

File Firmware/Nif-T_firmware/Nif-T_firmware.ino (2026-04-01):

/*
  Nif-T Firmware (ESP32-WROOM-32E + LAN8720A)
  - Ethernet (LAN8720) using GPIO0 50MHz clock out
  - MQTT control for 8 relays
  - SK6812 MINI GRBW strip (10 LEDs) on GPIO17
  - Home Assistant MQTT Discovery

  Topics:
    nif-t/<chipid>/relay/<n>/set   payload: ON/OFF
    nif-t/<chipid>/relay/<n>/state payload: ON/OFF
    nif-t/<chipid>/led/set         payload: JSON {"state":"ON","brightness":0-255,"r":0-255,"g":0-255,"b":0-255,"w":0-255}
    nif-t/<chipid>/led/state       same JSON

  If you use Home Assistant, discovery will auto-create entities.
*/

#include <WiFi.h>
#include <ETH.h>
#include <PubSubClient.h>
#include <Adafruit_NeoPixel.h>

// -------------------- USER CONFIG --------------------
static const char* MQTT_HOST = "192.168.1.10"; // <-- set to your broker / Home Assistant IP
static const uint16_t MQTT_PORT = 1883;

// If your relays are active-low, set to true:
static const bool RELAY_ACTIVE_LOW = false;

// Relay 8 shares GPIO16 with buzzer.
// Set this true if GPIO16 is BUZZER_DATA, not relay8:
static const bool USE_GPIO16_AS_BUZZER = false;

// -------------------- PIN MAP (from your message) --------------------
// Ethernet PHY (LAN8720A)
static const int PIN_ETH_POWER_OR_RESET = 5;  // IO5 8720RST (Arduino ETH uses this as "power pin" toggle)
static const int PIN_ETH_MDC = 23;            // IO23 MDC
static const int PIN_ETH_MDIO = 18;           // IO18 MDIO
static const int PIN_ETH_ADDR = 0;            // common LAN8720 phy addr is 0 (sometimes 1)

// Ethernet MAC pins you listed (handled internally by ESP-IDF):
// GPIO19 TXD0
// GPIO22 TXD1
// GPIO21 TXEN
// GPIO25 RXD0 / MODE0
// GPIO26 RXD1 / MODE1
// GPIO27 CRS_DV / MODE2
// Clock: GPIO0 ETH_CLK + BOOT (we use ETH_CLOCK_GPIO0_IN)

// Relays
static const int PIN_RLY1 = 32;
static const int PIN_RLY2 = 33;
static const int PIN_RLY3 = 13;
static const int PIN_RLY4 = 14;
static const int PIN_RLY5 = 2;
static const int PIN_RLY6 = 4;
static const int PIN_RLY7 = 15;
static const int PIN_RLY8 = 16; // unless USE_GPIO16_AS_BUZZER

// LEDs
static const int PIN_LED_DATA = 17;
static const int LED_COUNT = 10;

// User button (GPIO34 is input-only; typically needs external pullup/pulldown)
static const int PIN_USER_BUTTON = 34;

// Buzzer
static const int PIN_BUZZER = 16;

// -------------------- GLOBALS --------------------
static bool ethConnected = false;

WiFiClient netClient;          // Works with ETH as well on ESP32 Arduino core
PubSubClient mqtt(netClient);

Adafruit_NeoPixel strip(LED_COUNT, PIN_LED_DATA, NEO_GRBW + NEO_KHZ800);

String baseTopic;              // nif-t/<chipid>
String deviceName;             // nif-t-<chipid>

bool relayState[8] = {false,false,false,false,false,false,false,false};

// LED “logical” state
bool ledOn = true;
uint8_t ledBri = 255;
uint8_t ledR=0, ledG=0, ledB=0, ledW=0;

// -------------------- HELPERS --------------------
static uint32_t chipId32() {
  uint64_t mac = ESP.getEfuseMac();
  return (uint32_t)(mac & 0xFFFFFFFF);
}

static const int RELAY_PINS[8] = {
  PIN_RLY1, PIN_RLY2, PIN_RLY3, PIN_RLY4, PIN_RLY5, PIN_RLY6, PIN_RLY7, PIN_RLY8
};

static void writeRelayHW(int idx, bool on) {
  if (idx < 0 || idx > 7) return;
  int pin = RELAY_PINS[idx];
  if (idx == 7 && USE_GPIO16_AS_BUZZER) return; // Relay8 disabled if buzzer uses GPIO16

  bool level = on;
  if (RELAY_ACTIVE_LOW) level = !on;
  digitalWrite(pin, level ? HIGH : LOW);
}

static void publishRelayState(int idx) {
  String t = baseTopic + "/relay/" + String(idx+1) + "/state";
  mqtt.publish(t.c_str(), relayState[idx] ? "ON" : "OFF", true);
}

static void setRelay(int idx, bool on, bool publish=true) {
  relayState[idx] = on;
  writeRelayHW(idx, on);
  if (publish && mqtt.connected()) publishRelayState(idx);
}

static void applyLed() {
  uint8_t r = ledOn ? ledR : 0;
  uint8_t g = ledOn ? ledG : 0;
  uint8_t b = ledOn ? ledB : 0;
  uint8_t w = ledOn ? ledW : 0;

  // Apply brightness by scaling channels (simple + predictable)
  auto scale = [&](uint8_t v)->uint8_t {
    return (uint16_t(v) * uint16_t(ledBri)) / 255;
  };

  uint32_t c = strip.Color(scale(r), scale(g), scale(b), scale(w));
  for (int i = 0; i < LED_COUNT; i++) strip.setPixelColor(i, c);
  strip.show();
}

static void publishLedState() {
  String t = baseTopic + "/led/state";
  // Minimal JSON (no extra deps)
  char buf[160];
  snprintf(buf, sizeof(buf),
           "{\"state\":\"%s\",\"brightness\":%u,\"r\":%u,\"g\":%u,\"b\":%u,\"w\":%u}",
           ledOn ? "ON" : "OFF",
           (unsigned)ledBri,
           (unsigned)ledR,(unsigned)ledG,(unsigned)ledB,(unsigned)ledW);
  mqtt.publish(t.c_str(), buf, true);
}

static bool parseJsonByte(const String& s, const char* key, uint8_t& out) {
  String k = String("\"") + key + "\":";
  int i = s.indexOf(k);
  if (i < 0) return false;
  i += k.length();
  while (i < (int)s.length() && (s[i] == ' ')) i++;
  int j = i;
  while (j < (int)s.length() && isDigit((unsigned char)s[j])) j++;
  if (j == i) return false;
  int v = s.substring(i, j).toInt();
  if (v < 0) v = 0;
  if (v > 255) v = 255;
  out = (uint8_t)v;
  return true;
}

static bool parseJsonState(const String& s, bool& outOn) {
  int i = s.indexOf("\"state\"");
  if (i < 0) return false;
  int q1 = s.indexOf('"', i + 7);
  if (q1 < 0) return false;
  int q2 = s.indexOf('"', q1 + 1);
  if (q2 < 0) return false;
  String val = s.substring(q1 + 1, q2);
  val.toUpperCase();
  outOn = (val == "ON");
  return true;
}

// -------------------- HOME ASSISTANT DISCOVERY --------------------
static void haPublishRelayDiscovery(int idx) {
  // discovery topic: homeassistant/switch/<unique>/relayN/config
  String uid = deviceName + "_relay_" + String(idx+1);
  String topic = "homeassistant/switch/" + uid + "/config";

  String name = "Nif-T Relay " + String(idx+1);
  String cmd_t = baseTopic + "/relay/" + String(idx+1) + "/set";
  String st_t  = baseTopic + "/relay/" + String(idx+1) + "/state";
  String av_t  = baseTopic + "/availability";

  // device block ties everything into one device in HA
  String payload =
    "{"
      "\"name\":\"" + name + "\","
      "\"unique_id\":\"" + uid + "\","
      "\"command_topic\":\"" + cmd_t + "\","
      "\"state_topic\":\"" + st_t + "\","
      "\"payload_on\":\"ON\","
      "\"payload_off\":\"OFF\","
      "\"availability_topic\":\"" + av_t + "\","
      "\"payload_available\":\"online\","
      "\"payload_not_available\":\"offline\","
      "\"retain\":true,"
      "\"device\":{"
        "\"identifiers\":[\"" + deviceName + "\"],"
        "\"name\":\"" + deviceName + "\","
        "\"model\":\"Nif-T\","
        "\"manufacturer\":\"Custom\""
      "}"
    "}";

  mqtt.publish(topic.c_str(), payload.c_str(), true);
}

static void haPublishLedDiscovery() {
  // Make this a "light" entity
  String uid = deviceName + "_led";
  String topic = "homeassistant/light/" + uid + "/config";

  String name = "Nif-T LEDs";
  String cmd_t = baseTopic + "/led/set";
  String st_t  = baseTopic + "/led/state";
  String av_t  = baseTopic + "/availability";

  String payload =
    "{"
      "\"name\":\"" + name + "\","
      "\"unique_id\":\"" + uid + "\","
      "\"command_topic\":\"" + cmd_t + "\","
      "\"state_topic\":\"" + st_t + "\","
      "\"availability_topic\":\"" + av_t + "\","
      "\"payload_available\":\"online\","
      "\"payload_not_available\":\"offline\","
      "\"retain\":true,"
      "\"supported_color_modes\":[\"rgbw\"],"
      "\"brightness\":true,"
      "\"schema\":\"json\","
      "\"device\":{"
        "\"identifiers\":[\"" + deviceName + "\"],"
        "\"name\":\"" + deviceName + "\","
        "\"model\":\"Nif-T\","
        "\"manufacturer\":\"Custom\""
      "}"
    "}";

  mqtt.publish(topic.c_str(), payload.c_str(), true);
}

static void haPublishAllDiscovery() {
  for (int i = 0; i < 8; i++) {
    if (i == 7 && USE_GPIO16_AS_BUZZER) continue;
    haPublishRelayDiscovery(i);
  }
  haPublishLedDiscovery();
}

// -------------------- MQTT CALLBACK --------------------
static void mqttCallback(char* topic, byte* payload, unsigned int length) {
  String t(topic);
  String msg;
  msg.reserve(length + 1);
  for (unsigned int i = 0; i < length; i++) msg += (char)payload[i];
  msg.trim();

  // Relay set: nif-t/<chipid>/relay/N/set
  for (int i = 0; i < 8; i++) {
    String rt = baseTopic + "/relay/" + String(i+1) + "/set";
    if (t == rt) {
      String up = msg; up.toUpperCase();
      setRelay(i, (up == "ON" || up == "1" || up == "TRUE"));
      return;
    }
  }

  // LED set: nif-t/<chipid>/led/set   (JSON)
  if (t == (baseTopic + "/led/set")) {
    bool newOn = ledOn;
    uint8_t v;

    parseJsonState(msg, newOn);

    if (parseJsonByte(msg, "brightness", v)) ledBri = v;
    if (parseJsonByte(msg, "r", v)) ledR = v;
    if (parseJsonByte(msg, "g", v)) ledG = v;
    if (parseJsonByte(msg, "b", v)) ledB = v;
    if (parseJsonByte(msg, "w", v)) ledW = v;

    ledOn = newOn;
    applyLed();
    if (mqtt.connected()) publishLedState();
    return;
  }
}

// -------------------- ETHERNET EVENTS --------------------
#if ESP_ARDUINO_VERSION_MAJOR >= 3
static void WiFiEvent(arduino_event_id_t event, arduino_event_info_t info) {
  switch (event) {
    case ARDUINO_EVENT_ETH_START:
      ETH.setHostname(deviceName.c_str());
      break;

    case ARDUINO_EVENT_ETH_GOT_IP:
      ethConnected = true;
      Serial.print("ETH IP: ");
      Serial.println(ETH.localIP());
      break;

    case ARDUINO_EVENT_ETH_DISCONNECTED:
    case ARDUINO_EVENT_ETH_STOP:
      ethConnected = false;
      break;

    default:
      break;
  }
}
#else
static void WiFiEvent(WiFiEvent_t event) {
  switch (event) {
    case SYSTEM_EVENT_ETH_START:
      ETH.setHostname(deviceName.c_str());
      break;

    case SYSTEM_EVENT_ETH_GOT_IP:
      ethConnected = true;
      Serial.print("ETH IP: ");
      Serial.println(ETH.localIP());
      break;

    case SYSTEM_EVENT_ETH_DISCONNECTED:
    case SYSTEM_EVENT_ETH_STOP:
      ethConnected = false;
      break;

    default:
      break;
  }
}
#endif


// -------------------- MQTT CONNECT --------------------
static void mqttConnect() {
  if (!ethConnected) return;
  if (mqtt.connected()) return;

  Serial.println("Connecting MQTT...");

  // LWT availability
  String avail = baseTopic + "/availability";

  // Client ID
  String clientId = deviceName;

  if (mqtt.connect(clientId.c_str(), avail.c_str(), 0, true, "offline")) {
    mqtt.publish(avail.c_str(), "online", true);

    // Subscribe
    for (int i = 0; i < 8; i++) {
      if (i == 7 && USE_GPIO16_AS_BUZZER) continue;
      String rt = baseTopic + "/relay/" + String(i+1) + "/set";
      mqtt.subscribe(rt.c_str());
    }
    mqtt.subscribe((baseTopic + "/led/set").c_str());

    // Discovery + initial states
    haPublishAllDiscovery();

    for (int i = 0; i < 8; i++) {
      if (i == 7 && USE_GPIO16_AS_BUZZER) continue;
      publishRelayState(i);
    }
    publishLedState();

    Serial.println("MQTT connected.");
  } else {
    Serial.print("MQTT failed, rc=");
    Serial.println(mqtt.state());
  }
}

// -------------------- SETUP/LOOP --------------------
void setup() {
  Serial.begin(115200);
  delay(200);

  uint32_t id = chipId32();
  deviceName = "nif-t-" + String(id, HEX);
  baseTopic  = "nif-t/" + String(id, HEX);

  Serial.println();
  Serial.println("Booting " + deviceName);

  // GPIO init
  for (int i = 0; i < 8; i++) {
    if (i == 7 && USE_GPIO16_AS_BUZZER) continue;
    pinMode(RELAY_PINS[i], OUTPUT);
  }

  // default all relays OFF
  for (int i = 0; i < 8; i++) {
    if (i == 7 && USE_GPIO16_AS_BUZZER) continue;
    setRelay(i, false, false);
  }

  // Button input (GPIO34 has no internal pullup)
  pinMode(PIN_USER_BUTTON, INPUT);

  // LEDs
  strip.begin();
  strip.show();
  applyLed();

  // Ethernet
  WiFi.onEvent(WiFiEvent);

  // IMPORTANT: clock mode uses GPIO0 OUT 50MHz as you specified
  // LAN8720A, PHY addr 0, reset/power pin on GPIO5
  ETH.begin(
    PIN_ETH_ADDR,            // phy_addr
    PIN_ETH_POWER_OR_RESET,  // power / reset pin (or -1 if not used)
    PIN_ETH_MDC,             // mdc
    PIN_ETH_MDIO,            // mdio
    ETH_PHY_LAN8720,         // type
    ETH_CLOCK_GPIO0_IN       // clock mode (GPIO0 inputs 50MHz)
  );



  // MQTT
  mqtt.setServer(MQTT_HOST, MQTT_PORT);
  mqtt.setCallback(mqttCallback);
}

void loop() {
  mqttConnect();
  mqtt.loop();

  // Example: button toggles Relay1 (optional convenience)
  static int lastBtn = 0;
  int btn = digitalRead(PIN_USER_BUTTON);
  if (btn != lastBtn) {
    lastBtn = btn;
    // if your button is active-low, you may want: if (btn == LOW)
    if (btn == HIGH) {
      setRelay(0, !relayState[0]);
      // simple beep if buzzer mode
      if (USE_GPIO16_AS_BUZZER) {
        pinMode(PIN_BUZZER, OUTPUT);
        digitalWrite(PIN_BUZZER, HIGH);
        delay(40);
        digitalWrite(PIN_BUZZER, LOW);
      }
    }
  }

  delay(5);
}

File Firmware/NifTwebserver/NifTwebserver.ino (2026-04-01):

#include <Arduino.h>
#include <WiFi.h>
#include <WebServer.h>
#include <Adafruit_NeoPixel.h>

// ==================== BRANDING / USER CONFIG ====================
static const char* PRODUCT_NAME = "Nif-T";
static const char* HOSTNAME     = "nif-t";

static const char* WIFI_SSID = "wifiname";
static const char* WIFI_PASS = "password";

static const bool RELAY_ACTIVE_LOW = false;

#define ENABLE_WIFI      1
#define ENABLE_ETHERNET  0
#define ENABLE_BUZZER_DEFAULT 1
#define ENABLE_LEDS_DEFAULT   1

// -------------------- PIN MAP --------------------
static const int PIN_ETH_POWER_OR_RESET = 5;
static const int PIN_ETH_MDC = 23;
static const int PIN_ETH_MDIO = 18;
static const int PIN_ETH_ADDR = 0;

static const int PIN_LED_DATA = 17;
static const int LED_COUNT    = 10;
static const int PIN_BUTTON   = 34;   // external pull-up: pressed = LOW
static const int PIN_BUZZER   = 16;

static const int PIN_RLY1 = 32;
static const int PIN_RLY2 = 33;
static const int PIN_RLY3 = 13;
static const int PIN_RLY4 = 14;
static const int PIN_RLY5 = 2;
static const int PIN_RLY6 = 4;
static const int PIN_RLY7 = 15;
static const int PIN_RLY8 = 16; // shared with buzzer

static const int PIN_AUX1 = 37;
static const int PIN_AUX2 = 36;
static const int PIN_AUX3 = 35;

#if ENABLE_ETHERNET
  #define ETH_PHY_TYPE  ETH_PHY_LAN8720
  #define ETH_PHY_ADDR  PIN_ETH_ADDR
  #define ETH_PHY_MDC   PIN_ETH_MDC
  #define ETH_PHY_MDIO  PIN_ETH_MDIO
  #define ETH_PHY_POWER -1
  #define ETH_CLK_MODE  ETH_CLOCK_GPIO0_IN
  #include <ETH.h>
#endif

#define PIXEL_TYPE (NEO_GRB + NEO_KHZ800)
Adafruit_NeoPixel strip(LED_COUNT, PIN_LED_DATA, PIXEL_TYPE);
WebServer server(80);

// ==================== SETTINGS ====================
static const uint8_t  LED_BRIGHTNESS        = 180;
static const uint32_t FRAME_MS              = 25;
static const uint32_t BUTTON_DEBOUNCE_MS    = 30;
static const uint32_t MULTICLICK_TIMEOUT_MS = 420;
static const uint8_t  RICKROLL_CLICK_COUNT  = 5;
static const uint32_t WIFI_RETRY_MS         = 15000;
static const uint32_t WIFI_FAILOVER_MS      = 10000;
static const bool     DEFAULT_SHARED_LINES_ON = true;

// Fallback hotspot
static const char* FALLBACK_AP_SSID = "Nif-T";
static const char* FALLBACK_AP_PASS = "17171717";

// ==================== EFFECTS ====================
enum EffectMode : uint8_t {
  MODE_RAINBOW_PHYSICAL = 0,
  MODE_PURPLE_FIRE      = 1,
  MODE_COUNT
};

EffectMode effectMode = MODE_RAINBOW_PHYSICAL;

// Physical LED layout
// Rows top -> bottom:
// y=0:  5, 2
// y=1:  6, 1
// y=2:  7, 3
// y=3:  8, 4
// y=4:  9,10
static const int8_t physToIndex[5][2] = {
  {4, 1},
  {5, 0},
  {6, 2},
  {7, 3},
  {8, 9}
};

static const uint8_t ledX[LED_COUNT] = {1,1,1,1,0,0,0,0,0,1};
static const uint8_t ledY[LED_COUNT] = {1,0,2,3,0,1,2,3,4,4};

static const uint8_t rowLevelPct[5] = {4, 8, 18, 42, 100};
uint8_t heat[5][2] = {0};

// ==================== BREAKOUT / DEVICE MODEL ====================
enum DeviceType : uint8_t {
  DEV_DISABLED    = 0,
  DEV_DIGITAL_OUT = 1,
  DEV_PWM         = 2,
  DEV_SERVO       = 3,
  DEV_INPUT       = 4
};

enum RelayMirrorState : uint8_t {
  RELAY_RESERVED  = 0,
  RELAY_UNMANAGED = 1,
  RELAY_OFF       = 2,
  RELAY_ON        = 3,
  RELAY_DRIVEN    = 4
};

struct PinMeta {
  uint8_t pin;
  const char* defaultLabel;
  bool inputOnly;
  int8_t relayIndex;
  bool ledShared;
  bool buzzerShared;
};

static const PinMeta PIN_META[] = {
  { 2,  "GPIO2",  false, 4, false, false },
  { 4,  "GPIO4",  false, 5, false, false },
  { 15, "GPIO15", false, 6, false, false },
  { 16, "GPIO16", false, 7, false, true  },
  { 17, "GPIO17", false, -1, true, false },
  { 13, "GPIO13", false, 2, false, false },
  { 14, "GPIO14", false, 3, false, false },
  { 32, "GPIO32", false, 0, false, false },
  { 33, "GPIO33", false, 1, false, false },
  { 37, "GPIO37", true,  -1, false, false },
  { 36, "GPIO36", true,  -1, false, false },
  { 35, "GPIO35", true,  -1, false, false }
};

static const uint8_t PIN_DEVICE_COUNT = sizeof(PIN_META) / sizeof(PIN_META[0]);

struct PinDevice {
  uint8_t pin;
  char label[24];
  DeviceType type;
  int value;
  int freq;
  bool inputOnly;
  int8_t relayIndex;
  bool ledShared;
  bool buzzerShared;
  bool pwmAttached;
};

PinDevice devices[PIN_DEVICE_COUNT];

static const uint8_t relayPins[8] = {
  PIN_RLY1, PIN_RLY2, PIN_RLY3, PIN_RLY4,
  PIN_RLY5, PIN_RLY6, PIN_RLY7, PIN_RLY8
};

// ==================== NETWORK STATE ====================
#if ENABLE_ETHERNET
volatile bool ethConnected = false;
#endif

uint32_t lastWiFiAttemptMs = 0;
uint32_t wifiConnectStartMs = 0;
bool apFallbackActive = false;

// ==================== SYSTEM FLAGS ====================
bool ledEngineEnabled = ENABLE_LEDS_DEFAULT;
bool buzzerEnabled    = ENABLE_BUZZER_DEFAULT;

// ==================== BUTTON STATE ====================
int btnLastReading = HIGH;
int btnStableState = HIGH;
uint32_t btnLastChangeMs = 0;
uint8_t pendingClicks = 0;
uint32_t lastClickReleaseMs = 0;

// ==================== TIMING ====================
uint32_t lastFrameMs = 0;
uint16_t tick = 0;
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

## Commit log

2025-11-26 Added Components
    [Nif-T.kicad_pcb, Nif-T.kicad_sch]
2025-11-28 Big ol trip
    Worked on this while traveling.
    [Nif-T.kicad_pcb, Nif-T.kicad_sch, Nif-T_power_and_IO.kicad_sch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]
2025-12-05 PCB Reconfigured and Rerouted
    [Nif-T.kicad_pcb, Nif-T.kicad_sch, Nif-T_power_and_IO.kicad_sch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]
2025-12-12 Add Nif-T ESP32 firmware
    Added initial Nif-T_firmware.ino for ESP32-WROOM-32E with LAN8720A Ethernet, MQTT relay/LED control, and Home Assistant discovery.
    [Nif-T.kicad_pcb]
2025-12-12 Add README and PCB Renders
2025-12-13 BOM and Gerbers Done
    [BOM.csv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]
2025-12-18 Impedance matching and 4 layers
    The PCB is now a 4 layer board for better ground pour coverage and to allow for proper impedance matching as needed by ethernet.
    PCB Toolkit was used to calculate the new widths needed for proper ethernet trace impedance.
    [Nif-T-B_Cu.gbr, Nif-T-B_Mask.gbr, Nif-T-B_Paste.gbr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]
2025-12-31 Updated Gerbers
    [Nif-T-B_Cu.gbr, Nif-T-B_Mask.gbr, Nif-T-B_Paste.gbr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]
